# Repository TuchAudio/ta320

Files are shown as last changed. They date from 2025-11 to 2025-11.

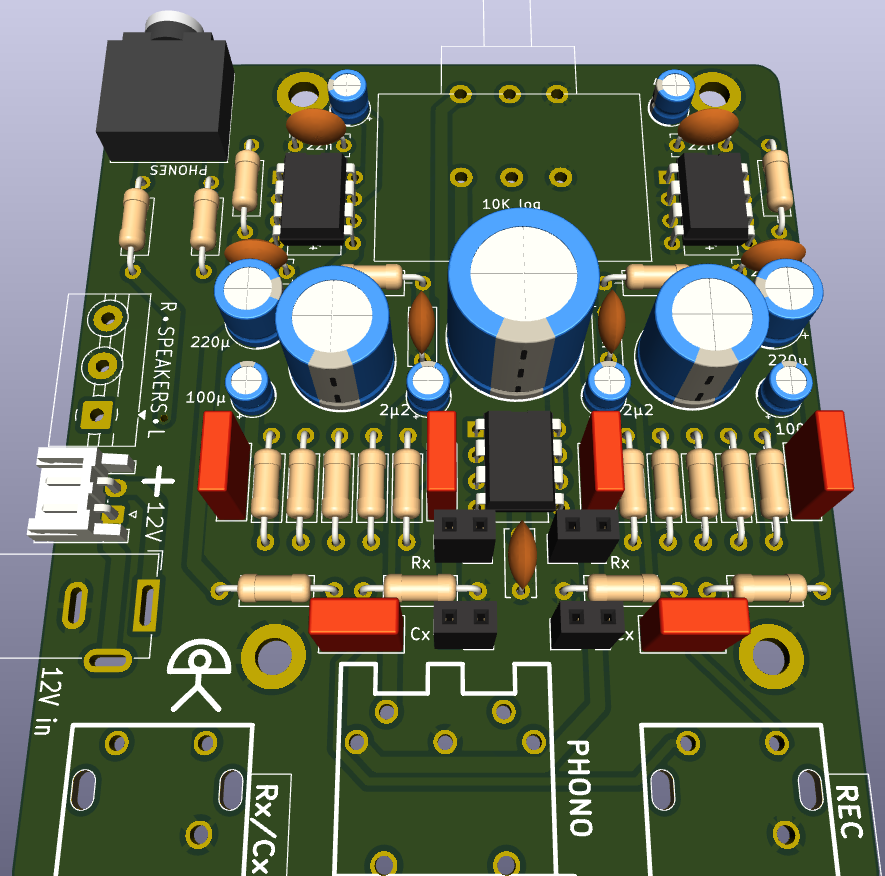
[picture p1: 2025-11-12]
pics/320-render.png

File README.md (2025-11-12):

# ta320
Compact, integrated amplifier with Phono pre-amp and headphone output

## Purpose
A convenient way to monitor the output of a **Phono cartridge**. The moderate _output power_ (**~1.5 W RMS**) is enough for most uses, while a convenient **headphone output** is provided (thru 100 ohm _attenuation resistors_)

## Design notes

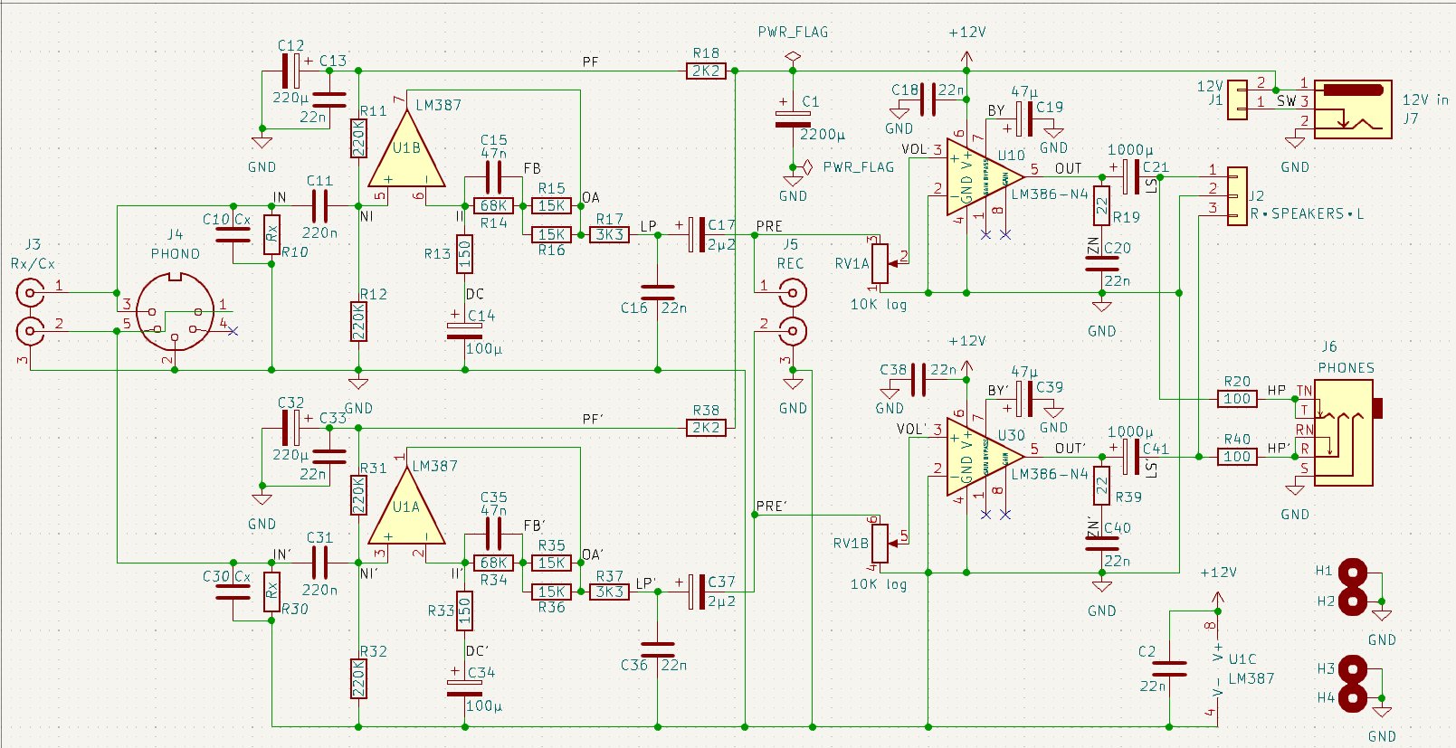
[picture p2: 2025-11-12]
pics/320-schematic.png

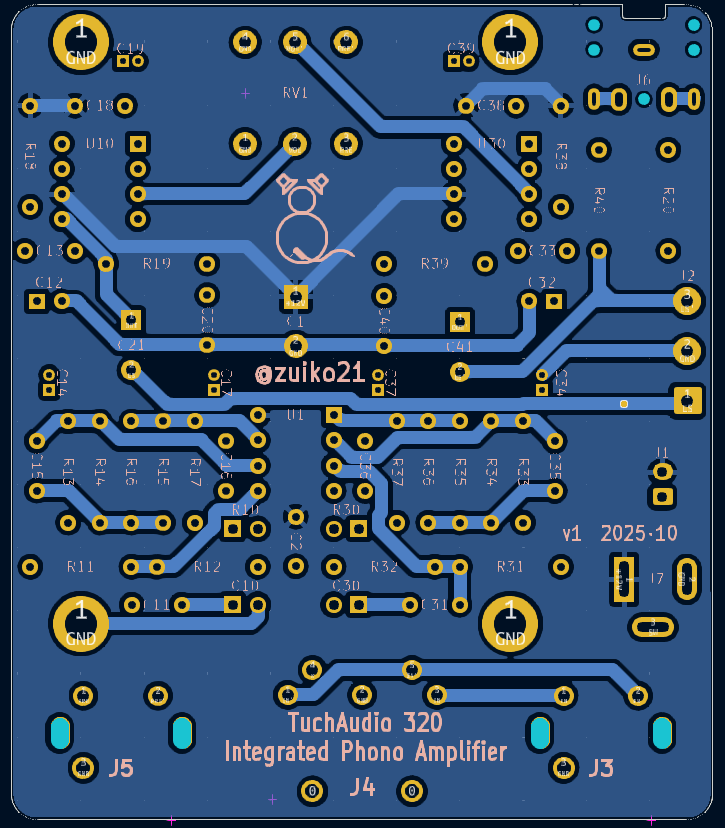
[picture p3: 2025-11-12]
pics/320-pcb-back.png

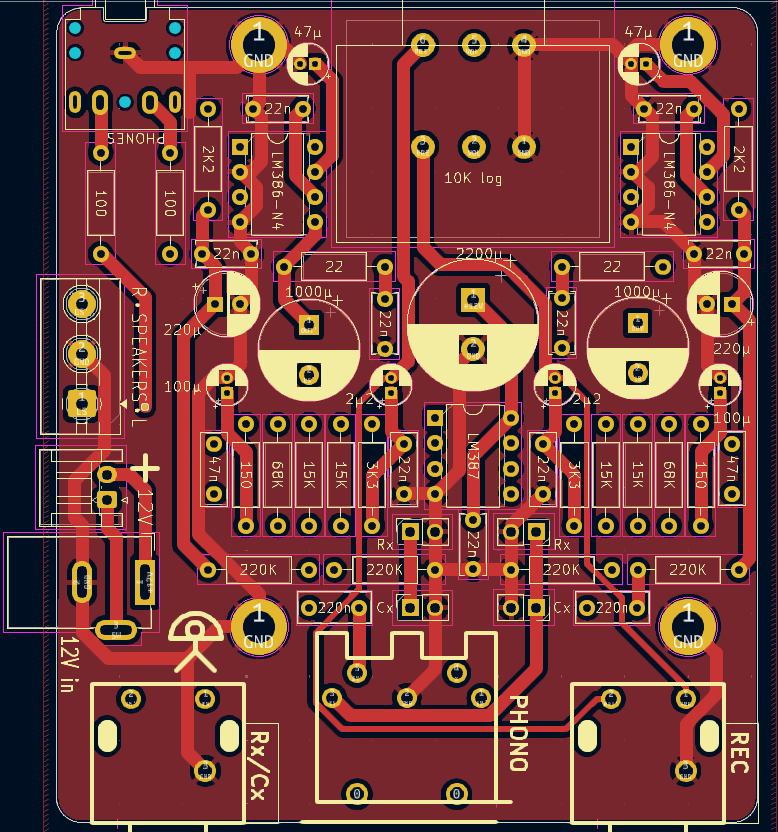
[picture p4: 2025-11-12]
pics/320-pcb-front.png

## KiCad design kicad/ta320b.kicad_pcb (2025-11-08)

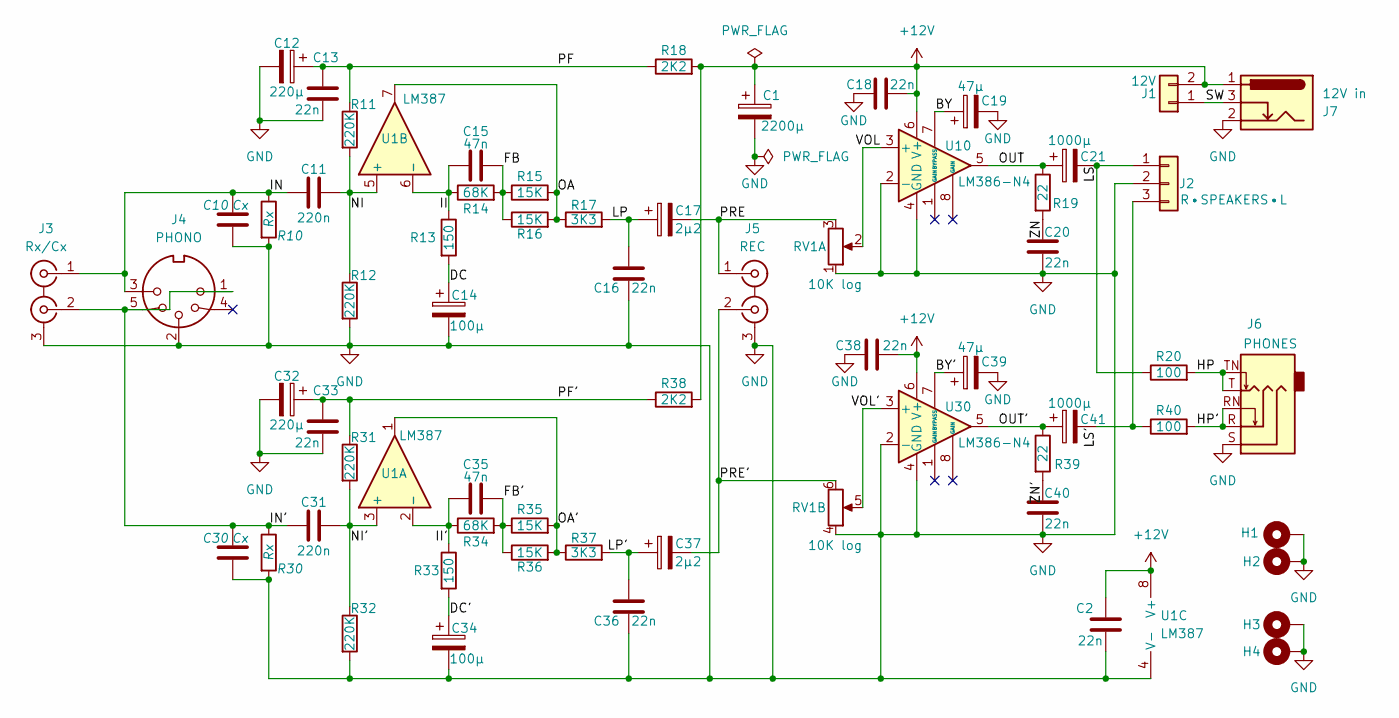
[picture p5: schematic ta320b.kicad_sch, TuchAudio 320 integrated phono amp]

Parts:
C1: 2200µ; CP_Radial_D13.0mm_P5.00mm
C2, C13, C18, C20, C33, C38, C40: 22n; C_Disc_D6.0mm_W2.5mm_P5.00mm
C10, C30: Cx; PinSocket_1x02_P2.54mm_Vertical
C11, C31: 220n; C_Rect_L7.2mm_W3.0mm_P5.00mm_FKS2_FKP2_MKS2_MKP2
C12, C32: 220µ; CP_Radial_D6.3mm_P2.50mm
C14, C34: 100µ; CP_Radial_D4.0mm_P1.50mm
C15, C35: 47n; C_Rect_L7.2mm_W2.5mm_P5.00mm_FKS2_FKP2_MKS2_MKP2
C16, C36: 22n; C_Rect_L7.2mm_W2.5mm_P5.00mm_FKS2_FKP2_MKS2_MKP2
C17, C37: 2µ2; CP_Radial_D4.0mm_P1.50mm
C19, C39: 47µ; CP_Radial_D4.0mm_P1.50mm
C21, C41: 1000µ; CP_Radial_D10.0mm_P5.00mm
H1, H2, H3, H4: MountingHole_Pad; MountingHole_3.2mm_M3_DIN965_Pad
J1: 12V; JST_EH_S2B-EH_1x02_P2.50mm_Horizontal
J2: R•SPEAKERS•L; TerminalBlock_MaiXu_MX126-5.0-03P_1x03_P5.00mm
J3: Rx/Cx; 2xRCA_vertical
J4: PHONO; DIN 5-180deg
J5: REC; 2xRCA_vertical
J6: PHONES; Jack_3.5mm_CUI_SJ1-3525N_Horizontal
J7: 12V in; BarrelJack_GCT_DCJ200-10-A_Horizontal
R10, R30: Rx; PinSocket_1x02_P2.54mm_Vertical
R11, R12, R31, R32: 220K; R_Axial_DIN0207_L6.3mm_D2.5mm_P10.16mm_Horizontal
R13, R33: 150; R_Axial_DIN0207_L6.3mm_D2.5mm_P10.16mm_Horizontal
R14, R34: 68K; R_Axial_DIN0207_L6.3mm_D2.5mm_P10.16mm_Horizontal
R15, R16, R35, R36: 15K; R_Axial_DIN0207_L6.3mm_D2.5mm_P10.16mm_Horizontal
R17, R37: 3K3; R_Axial_DIN0207_L6.3mm_D2.5mm_P10.16mm_Horizontal
R18, R38: 2K2; R_Axial_DIN0207_L6.3mm_D2.5mm_P10.16mm_Horizontal
R19, R39: 22; R_Axial_DIN0207_L6.3mm_D2.5mm_P10.16mm_Horizontal
R20, R40: 100; R_Axial_DIN0207_L6.3mm_D2.5mm_P10.16mm_Horizontal
RV1: 10K log; Potentiometer_Alps_225G_Dual_Horizontal
U1: LM387; DIP-8_W7.62mm
U10, U30: LM386-N4; DIP-8_W7.62mm

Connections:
+12V: C1.1, C2.2, C18.2, C38.2, J1.2, J7.1, R18.2, R38.2, U1.8 (V+), U10.6 (V+), U30.6 (V+)
/BY: C19.1, U10.7 (BYPASS)
/BY': C39.1, U30.7 (BYPASS)
/DC: C14.1, R13.2
/DC': C34.1, R33.2
/FB: C15.2, R14.2, R15.1, R16.1
/FB': C35.2, R34.2, R35.1, R36.1
/HP: J6.T, J6.TN, R20.2
/HP': J6.R, J6.RN, R40.2
/II: C15.1, R13.1, R14.1, U1.6 (-)
/II': C35.1, R33.1, R34.1, U1.2 (-)
/IN: C10.1, C11.1, J3.1 (IN1), J4.3, R10.1
/IN': C30.1, C31.1, J3.2 (IN2), J4.1, J4.5, R30.1
/LP: C16.2, C17.1, R17.2
/LP': C36.2, C37.1, R37.2
/LS: C21.2, J2.1, R20.1
/LS': C41.2, J2.3, R40.1
/NI: C11.2, R11.2, R12.1, U1.5 (+)
/NI': C31.2, R31.2, R32.1, U1.3 (+)
/OA: R15.2, R16.2, R17.1, U1.7
/OA': R35.2, R36.2, R37.1, U1.1
/OUT: C21.1, R19.1, U10.5
/OUT': C41.1, R39.1, U30.5
/PF: C12.1, C13.2, R11.1, R18.1
/PF': C32.1, C33.2, R31.1, R38.1
/PRE: C17.2, J5.1 (IN1), RV1.3
/PRE': C37.2, J5.2 (IN2), RV1.6
/SW: J1.1, J7.3
/VOL: RV1.2, U10.3 (+)
/VOL': RV1.5, U30.3 (+)
/ZN: C20.1, R19.2
/ZN': C40.1, R39.2
GND: C1.2, C2.1, C10.2, C12.2, C13.1, C14.2, C16.1, C18.1, C19.2, C20.2, C30.2, C32.2, C33.1, C34.2, C36.1, C38.1, C39.2, C40.2, H1.1, H2.1, H3.1, H4.1, J2.2, J3.3 (EXT), J4.2, J5.3 (EXT), J6.S, J7.2, R10.2, R12.2, R30.2, R32.2, RV1.1, RV1.4, U1.4 (V-), U10.2 (-), U10.4 (GND), U30.2 (-), U30.4 (GND)

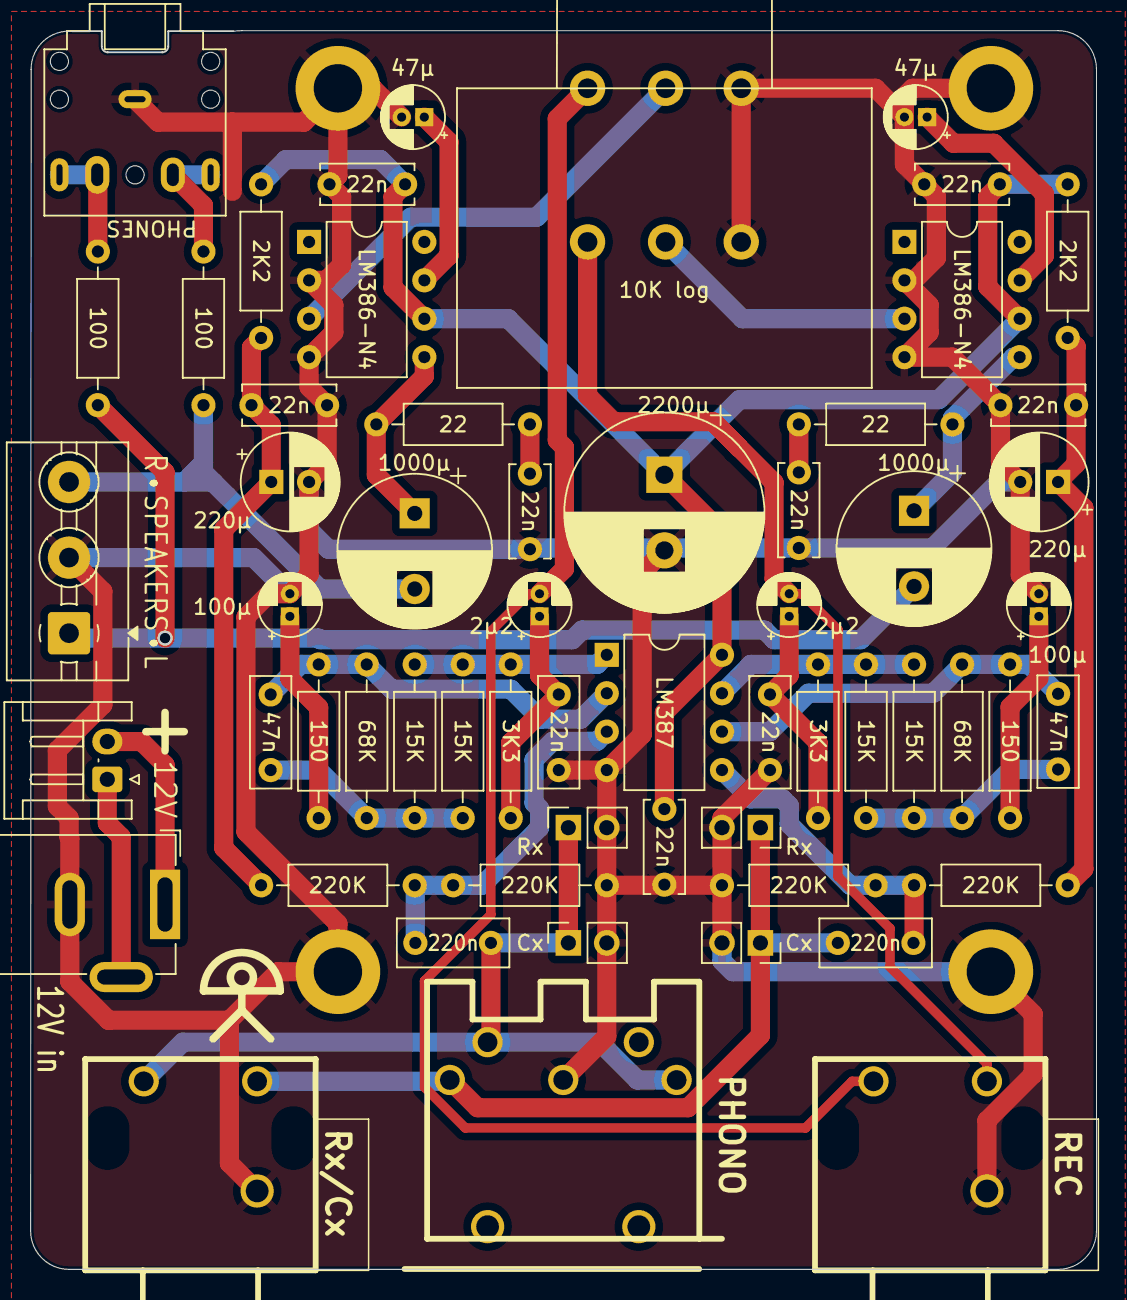
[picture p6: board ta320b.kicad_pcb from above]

Board: 2 copper layers, 70.5 x 81.9 mm, 63 parts (0 on the bottom side), 33 nets.
